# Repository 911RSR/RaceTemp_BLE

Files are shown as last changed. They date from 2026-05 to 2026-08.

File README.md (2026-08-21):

# RaceTemp_BLE

RaceTemp_BLE is an STM32WB55 based Bluetooth Low Energy sensor bridge for
RaceChrono. It reads local sensors, packages the measurements as RaceChrono
DIY CAN/BLE messages, and lets RaceChrono log them as if they came from a CAN
bus.

The project is based on the RaceChrono BLE DIY device idea from Aollin's demo
project:

https://github.com/aollin/racechrono-ble-diy-device

RaceTemp adds the temperature, pressure, thermocouple, RPM, engine-hours, and
engine-revolutions logic used by this project.

## Current Status

This is still a work in progress, but has som "track record" as it's 
the only logger we have used for track days and races in 2026.   

Implemented:

- BLE device name: `RaceTemp`
- RaceChrono-compatible CAN message characteristic
- Optional RaceChrono CAN filter handling
- ADC based MAP and NTC readings
- MAX31855 thermocouple support
- MAX31856 thermocouple support
- Ignition input based RPM measurement
- Engine operating hours counter
- Engine revolutions counter
- Persistent storage of engine counters after the engine stops
- Optional raw measurement snapshot message

## Building
You can download the binary (Release/RaceTemp_BLE.elf) and flash it to an STM32WB55. 
Android field flashing has been tested with STlinkP (Android app), STLINK-V3MINIE, 
and the WeAct STM32WB board. One can of course also flash it via ST-Link and 
STM32CubeProgrammer on a PC.   

If you want to compile yourself on a PC with STM32CubeMX and STM32CubeIDE, then follow this 4-step guide: 
1. Open the project in STM32CubeMX and click "GENERATE CODE".
This should generate some code files and copy some library files.
2. Run the script: .\tools\fix-cubemx-ble-duplicates.ps1
See also my CubeMX-notes at the bottom of this page.
3. Open the project in STM32CubeIDE and build the `Debug` or `Release` configuration.
4. Connect the STLink debug probe and flash the binary.  

The intended BLE security setup is:
- Bonding enabled
- No passkey
- No MITM requirement
- No input/output capability
- Secure connections mandatory
- GATT caching enabled
- Static random address `C0:52:54:42:4C:45`
- Advertisement includes the complete local name `RaceTemp`
- Advertisement includes the RaceChrono DIY service UUID `0x1ff8`

If pairing fails after a firmware or security setting change, delete/forget the
old `RaceTemp` pairing on the phone and pair again.

## Hardware Notes

Target MCU:

- STM32WB55CGU

The project has been developed and tested on a WeAct STM32WB55 board.

Thermocouple IC options:

- MAX31855
- MAX31856

The thermocouple IC is selected at compile time in:

```text
Core/Inc/RaceTemp_config.h
```

## Thermocouple Polarity

Do not trust wire color blindly. For many Type K thermocouples using US/ANSI
colors, yellow is positive and red is negative. Other color standards and probe
suppliers may differ.

A quick practical TC polarity check:

1. Connect the thermocouple.
2. Read the thermocouple channel in RaceChrono.
3. Warm the thermocouple tip with your fingers, hot air, or a lighter from a
   safe distance.
4. If the temperature goes up, the polarity is correct.
5. If the temperature goes down or becomes negative, swap the two thermocouple
   wires.

## Configuring The Thermocouple IC In Firmware

Edit `Core/Inc/RaceTemp_config.h` and set:

```c
#define RACETEMP_THERMOCOUPLE_IC RACETEMP_THERMOCOUPLE_IC_MAX31855
```

or:

```c
#define RACETEMP_THERMOCOUPLE_IC RACETEMP_THERMOCOUPLE_IC_MAX31856
```
For MAX31856, also select the thermocouple type. 
K-Type is most common (for motorsport and exhaust temperature). 

The firmware sends the thermocouple data as raw IC bytes on CAN ID `0x13`.
RaceChrono then decodes those bytes with an equation. This keeps the firmware
simple and makes it possible to inspect status and fault bits from the IC.

## Persistent Engine Counters

PID `21` / CAN ID `0x15` is the stored engine operating time in hours. It is a
lifetime counter, not time since boot. PID `22` / CAN ID `0x16` is the stored
engine revolution counter.

The counters are stored in the last two 4 KB flash pages:

- `0x0807E000`
- `0x0807F000`

The linker script reserves those pages by limiting normal application flash to
`504K`. This makes the firmware image fail to link before it can overlap the
counter storage.

Expected flashing behavior:

- Flashing with "erase necessary pages only" should preserve the counters.
- Flashing with mass erase / full chip erase resets the counters to zero.
- Manually erasing pages `0x0807E000` or `0x0807F000` resets the counters.

The firmware writes the counters to flash when RPM times out after the engine
stops. If the RPM input is left floating during bench testing, false pulses can
increase the counters, so keep the RPM input at a defined level when it is not
connected to a signal source.

## Using With RaceChrono

1. Power the RaceTemp device.
2. Pair the phone with the BLE device named `RaceTemp`.
3. Open RaceChrono.
4. Add/connect it as a RaceChrono BLE DIY/CAN device.
5. Add custom CAN channels for the CAN IDs listed below.
6. Enable the channels you want to log.

RaceChrono may show CAN IDs in either hexadecimal or decimal form. For example,
`0x13` is decimal `19`.

RaceChrono equations are documented here:

https://racechrono.com/support/equations

The thermocouple equations below use RaceChrono's `bitsToInt()` function. In
RaceChrono, bit offset 0 is the most significant bit of payload byte 0.
For the MAX31855 and MAX31856 temperature channels, the recommended equations
below use `bytesToInt()` because they are easier to enter correctly on a phone.

## RaceChrono CAN Channels

Most RaceTemp channels are sent as little-endian 32-bit floats. For those
channels, use this RaceChrono equation:

```text
bytesToFloatLe(raw, 0, 4)
```

| CAN ID | Decimal | Channel | Payload | Unit | RaceChrono equation |
| --- | ---: | --- | --- | --- | --- |
| `0x0B` | 11 | MAP pressure | float32 little-endian | kPa | `bytesToFloatLe(raw, 0, 4)` |
| `0x0C` | 12 | MAP NTC temperature | float32 little-endian | deg C | `bytesToFloatLe(raw, 0, 4)` |
| `0x0D` | 13 | Volvo NTC temperature | float32 little-endian | deg C | `bytesToFloatLe(raw, 0, 4)` |
| `0x0E` | 14 | AC NTC temperature | float32 little-endian | deg C | `bytesToFloatLe(raw, 0, 4)` |
| `0x0F` | 15 | KOSO NTC temperature | float32 little-endian | deg C | `bytesToFloatLe(raw, 0, 4)` |
| `0x10` | 16 | STM32 MCU temperature | float32 little-endian | deg C | `bytesToFloatLe(raw, 0, 4)` |
| `0x11` | 17 | MAP raw ADC value | float32 little-endian | ADC count | `bytesToFloatLe(raw, 0, 4)` |
| `0x12` | 18 | NTC raw ADC value | float32 little-endian | ADC count | `bytesToFloatLe(raw, 0, 4)` |
| `0x13` | 19 | Thermocouple raw data | IC-specific raw bytes | deg C | See thermocouple sections below |
| `0x14` | 20 | Engine speed | float32 little-endian | RPM | `bytesToFloatLe(raw, 0, 4)` |
| `0x15` | 21 | Engine operating time | float32 little-endian | hours | `bytesToFloatLe(raw, 0, 4)` |
| `0x16` | 22 | Engine revolutions | float32 little-endian | rev | `bytesToFloatLe(raw, 0, 4)` |
| `0x17` | 23 | Ignition period | float32 little-endian | timer ticks | `bytesToFloatLe(raw, 0, 4)` |
| `0x18` | 24 | Ignition captures | float32 little-endian | count | `bytesToFloatLe(raw, 0, 4)` |
| `0x19` | 25 | Ignition rejects | float32 little-endian | count | `bytesToFloatLe(raw, 0, 4)` |
| `0x1A` | 26 | EGT temperature | float32 little-endian | deg C | `bytesToFloatLe(raw, 0, 4)` |
| `0x1B` | 27 | Engine speed peak hold | float32 little-endian | RPM | `bytesToFloatLe(raw, 0, 4)` |
| `0x1C` | 28 | EGT peak hold | float32 little-endian | deg C | `bytesToFloatLe(raw, 0, 4)` |
| `0x1D` | 29 | Engine speed filtered | float32 little-endian | RPM | `bytesToFloatLe(raw, 0, 4)` |
| `0x1E` | 30 | Thermocouple status | float32 little-endian | bitmask | `bytesToFloatLe(raw, 0, 4)` |
| `0x1F` | 31 | Thermocouple recoveries | float32 little-endian | count | `bytesToFloatLe(raw, 0, 4)` |
| `0x20` | 32 | Raw measurement snapshot | packed raw bytes | debug | See source layout |
| `0x21` | 33 | RPM fast packet | packed float32 little-endian values | RPM | See RPM fast packet below |

The peak hold channels keep a new maximum value visible for 5 seconds. The RPM
peak hold uses the filtered RPM channel so single noisy periods do not create
false peaks. After 5 seconds without a higher sample, the held channels return
to the current live value.

The filtered RPM channel is calculated from a short recent ignition-period
window with outlier trimming. It is intended for the driver display. The raw RPM
channel remains useful for ignition pickup debugging.

## RPM Fast Packet

CAN ID `0x21` is sent at 25 Hz. It packs the driver-facing RPM values into one
BLE notification:

| Offset | Channel | Unit | RaceChrono equation |
| ---: | --- | --- | --- |
| 0 | RPM raw | RPM | `bytesToFloatLe(raw, 0, 4)` |
| 4 | RPM filtered | RPM | `bytesToFloatLe(raw, 4, 4)` |
| 8 | RPM peak hold | RPM | `bytesToFloatLe(raw, 8, 4)` |

The individual RPM and ignition debug channels remain available at the slower
sensor publishing rate for comparison and troubleshooting.

Thermocouple status is a bitmask:

- `1`: current EGT sample is valid
- `2`: SPI/read error
- `4`: thermocouple IC fault bit set
- `8`: MAX31856 config readback mismatch/error
- `16`: recovery was triggered on this sample
- `32`: implausible thermocouple temperature

When the thermocouple sample is invalid, the EGT channel sends `0 C`. This
is intentionally obvious in the driver display and logs; the firmware does not
hold the last good EGT value.

## Reading MAX31855 In RaceChrono

When `RACETEMP_THERMOCOUPLE_IC_MAX31855` is selected, CAN ID `0x13` contains
the four raw bytes read from the MAX31855. The byte order is the same as the IC
SPI transfer: most significant byte first.

The MAX31855 thermocouple temperature is a signed 14-bit value with
0.25 deg C per bit.

Recommended RaceChrono equation:

```text
bytesToInt(raw, 0, 2) / 16.0
```

Equivalent bitfield equation:

```text
bitsToInt(raw, 0, 14) * 0.25
```

The `bytesToInt()` version works because the MAX31855 thermocouple value is
left-aligned in the first two raw bytes.

Useful notes:

- The MAX31855 fault flag is bit D16 of the 32-bit raw value.
- The low bits contain the IC-specific fault details.
- A separate RaceChrono status channel can use `bytesToUint(raw, 3, 1)` to show
  the lowest raw byte.
- If the thermocouple channel shows unrealistic values, first confirm that the
  RaceTemp firmware is built for MAX31855 and not MAX31856.

## Reading MAX31856 In RaceChrono

When `RACETEMP_THERMOCOUPLE_IC_MAX31856` is selected, CAN ID `0x13` contains
four bytes:

| Payload byte | Contents |
| ---: | --- |
| 0 | MAX31856 `LTCBH` register |
| 1 | MAX31856 `LTCBM` register |
| 2 | MAX31856 `LTCBL` register |
| 3 | MAX31856 fault/status register |

The MAX31856 thermocouple temperature is a signed 19-bit value with
0.0078125 deg C per bit.

Recommended RaceChrono equation:

```text
bytesToInt(raw, 0, 3) / 4096.0
```

Equivalent bitfield equation:

```text
bitsToInt(raw, 0, 19) * 0.0078125
```

The `bytesToInt()` version works because the MAX31856 thermocouple value is
left-aligned in the first three raw bytes.

Useful notes:

- Select the correct thermocouple type in `RaceTemp_config.h`.
- Payload byte 3 is the MAX31856 fault/status register.
- A separate RaceChrono status channel can use `bytesToUint(raw, 3, 1)`.
- If the temperature is wrong but changes with heat, check the selected
  thermocouple type first.
- If the value is completely wrong, confirm that RaceChrono is using the
  MAX31856 equation and not the MAX31855 equation.

## Raw Measurement Snapshot

CAN ID `0x20` is intended for development and debugging. It sends one packed
snapshot of the raw measurement buffer:

- ADC samples
- Thermocouple SPI bytes
- Ignition timing data

Normal RaceChrono logging should usually use the individual channels instead.
The raw snapshot is useful when checking new sensors or debugging conversion
logic.

## Notes About CubeMX Regeneration

Unfortunately the current version of CubeMX can make some mistakes (it can duplicate user-section
content in the BLE files), and some generated files contain project-specific
settings. After regenerating the code, run the cleanup script before building:

```powershell
powershell -ExecutionPolicy Bypass -File .\tools\fix-cubemx-ble-duplicates.ps1
```

The script removes duplicate CubeMX generated BLE functions, restores the
RaceChrono BLE callbacks, restores the BLE security/address settings used by
this project, and repairs the local linker script.

Important local linker-script repairs:

- Normal application flash is limited to `504K`.
- `PERSIST` reserves the last two 4 KB flash pages for engine counters.
- `MAPPING_TABLE` is placed at `0x20030000`.
- `MB_MEM1` and `.MB_MEM2` are placed in the CPU2 shared RAMB area.
- `.MB_MEM2` is 4-byte aligned so startup initialization does not fault.

The script also removes the extra generated HSEM lock before `MX_APPE_Init()`.
Leaving that duplicate lock in place can stall BLE startup or lead to an early
HardFault.

To re-generate the code from CubeMX:

1. Open the .ioc file in CubeMX and click "GENERATE CODE"
2. Run `tools/fix-cubemx-ble-duplicates.ps1`
3. Build in STM32CubeIDE
4. Check that pairing still works with `RaceTemp`

Keep project-specific RaceTemp logic in the RaceTemp source files where
possible. This reduces the amount of code that lives inside CubeMX user
sections.

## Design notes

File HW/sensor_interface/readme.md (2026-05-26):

A sensor interface PCB designed and ordered on NiNo's 22 years birthday.  
The PCB has four inputs: 
1) RPM -- engine speed
2) EGT -- exhaust gas temperature
3) NTC1 -- water temperature 
4) NTC2 -- cylinder head temperature
   
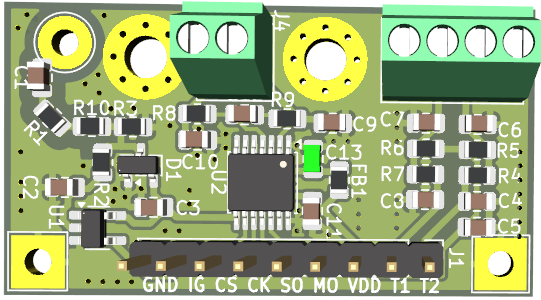
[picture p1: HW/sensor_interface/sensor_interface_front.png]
front side
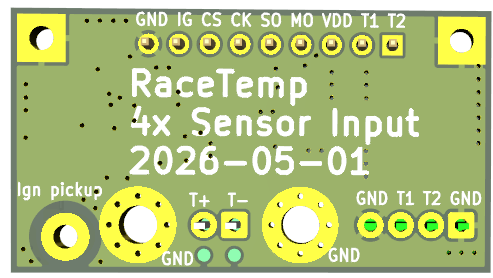
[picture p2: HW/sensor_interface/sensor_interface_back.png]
back side


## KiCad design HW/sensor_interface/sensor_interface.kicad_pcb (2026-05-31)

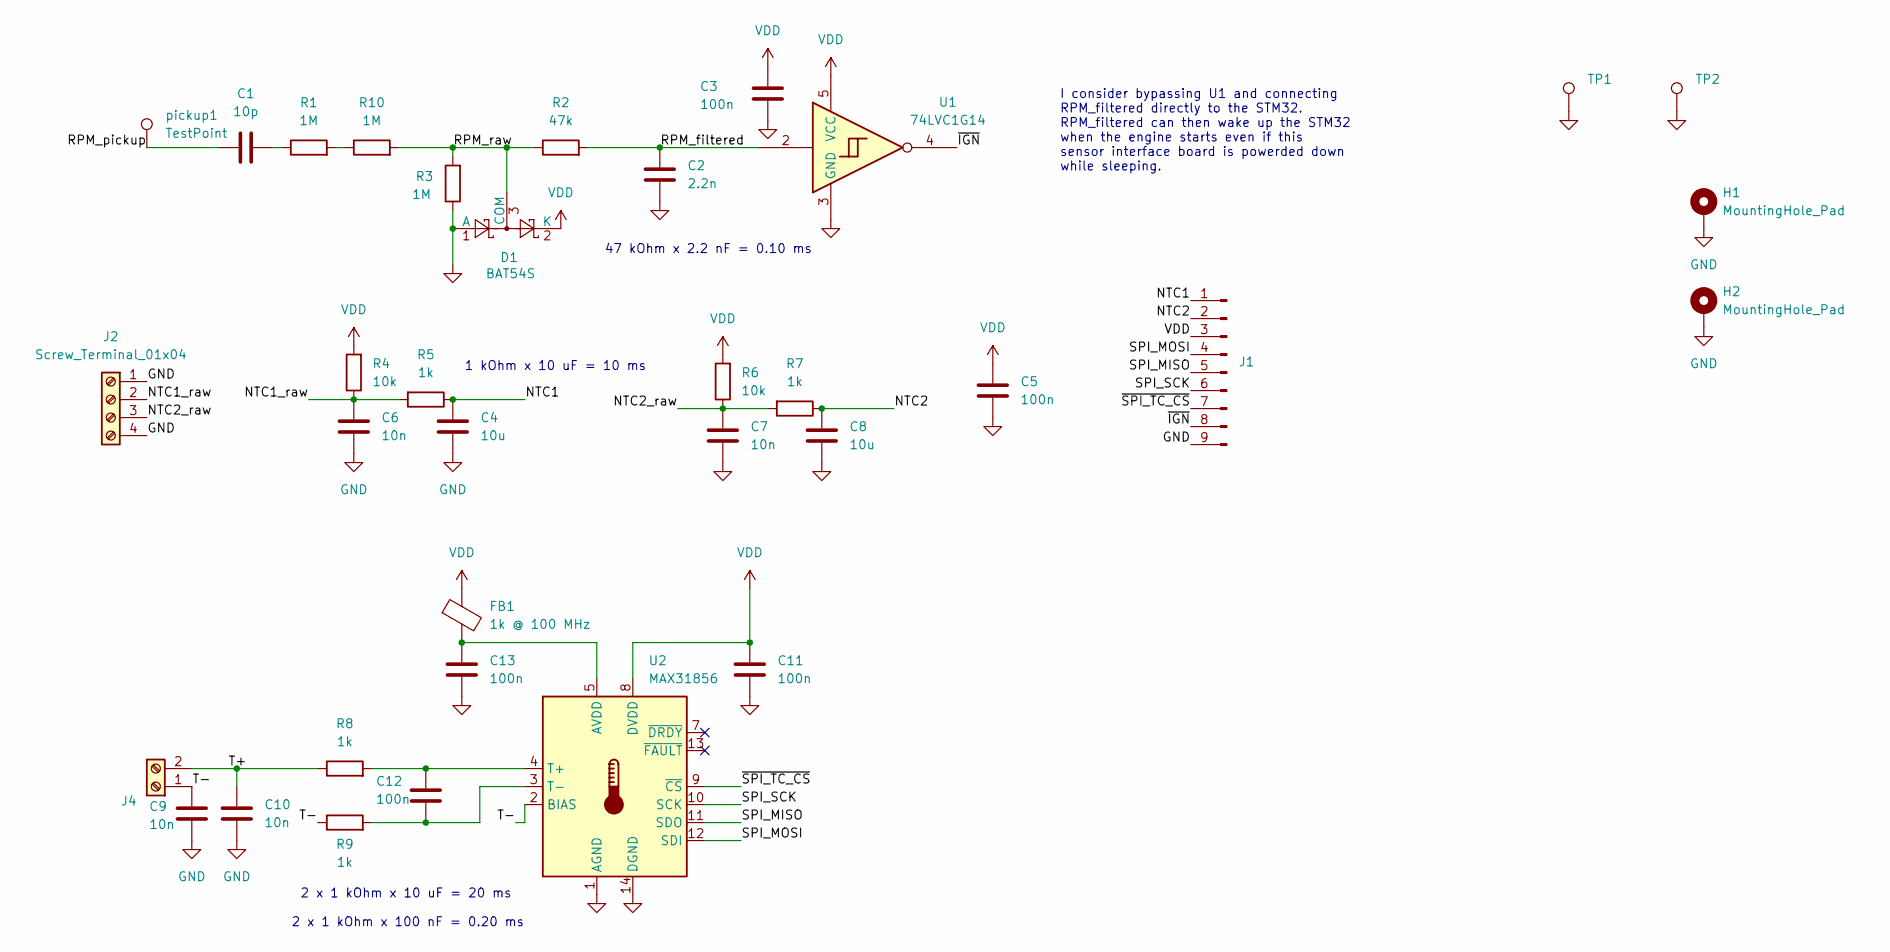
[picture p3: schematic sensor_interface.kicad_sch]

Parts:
C1: 10p; C_0805_2012Metric; MPN CC0805JRNPOCBN100
C2: 2.2n; C_0805_2012Metric; MPN C0805C222KAGECAUTO
C3, C5, C11, C12, C13: 100n; C_0805_2012Metric
C4, C8: 10u; C_0805_2012Metric
C6, C7, C9, C10: 10n; C_0805_2012Metric
D1: BAT54S; SOT-23; MPN BAT54S
FB1: 1k @ 100 MHz; R_0805_2012Metric
H1, H2: MountingHole_Pad; MountingHole_3.2mm_M3_Pad_Via
J1: Berg; PinHeader_1x09_P2.54mm_Vertical
J2: Screw_Terminal_01x04; TerminalBlock_Phoenix_MPT-0,5-4-2.54_1x04_P2.54mm_Horizontal
J4: Screw_Terminal; TerminalBlock_Phoenix_MPT-0,5-2-2.54_1x02_P2.54mm_Horizontal
R1: 1M; R_0805_2012Metric; MPN CRCW08051M00FKEA
R2: 47k; R_0805_2012Metric
R3, R10: 1M; R_0805_2012Metric
R4, R6: 10k; R_0805_2012Metric
R5, R7, R8, R9: 1k; R_0805_2012Metric
TP1, TP2: TestPoint; TestPoint_THTPad_4.0x4.0mm_Drill2.0mm
U1: 74LVC1G14; SOT-23-5_HandSoldering
U2: MAX31856; TSSOP-14_4.4x5mm_P0.65mm; MPN MAX31856MUD+T
pickup1: TestPoint; TestPoint_THTPad_D4.0mm_Drill2.0mm

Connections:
/NTC1: C4.2, J1.1, R5.1
/NTC1_raw: C6.2, J2.2, R4.1, R5.2
/NTC2: C8.2, J1.2, R7.1
/NTC2_raw: C7.2, J2.3, R6.1, R7.2
/RPM_filtered: C2.2, R2.2, U1.2
/RPM_pickup: C1.1, pickup1.1 (1_1)
/RPM_raw: D1.3 (COM), R2.1, R3.2, R10.2
/SPI_MISO: J1.5, U2.11 (SDO)
/SPI_MOSI: J1.4, U2.12 (SDI)
/SPI_SCK: J1.6, U2.10 (SCK)
/T+: C10.2, J4.2, R8.1
/T-: C9.2, J4.1, R9.1, U2.2 (BIAS)
/~IGN: J1.8, U1.4
/~SPI_TC_CS: J1.7, U2.9 (~CS)
GND: C2.1, C3.1, C4.1, C5.1, C6.1, C7.1, C8.1, C9.1, C10.1, C11.1, C13.1, D1.1 (A), H1.1 (1_1), H2.1 (1_1), J1.9, J2.1, J2.4, R3.1, TP1.1 (1_1), TP2.1 (1_1), U1.3 (GND), U2.1 (AGND), U2.14 (DGND)
unnamed: C1.2, R1.1
unnamed: R1.2, R10.1
unnamed: C13.2, FB1.2, U2.5 (AVDD)
unnamed: C12.2, R8.2, U2.4 (T+)
unnamed: C12.1, R9.2, U2.3 (T-)
VDD: C3.2, C5.2, C11.2, D1.2 (K), FB1.1, J1.3, R4.2, R6.2, U1.5 (VCC), U2.8 (DVDD)

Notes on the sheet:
2 x 1 kOhm x 10 uF = 20 ms
I consider bypassing U1 and connecting RPM_filtered directly to the STM32. RPM_filtered can then wake up the STM32 when the engine starts even if this sensor interface board is powerded down while sleeping.
47 kOhm x 2.2 nF = 0.10 ms
2 x 1 kOhm x 100 nF = 0.20 ms
1 kOhm x 10 uF = 10 ms

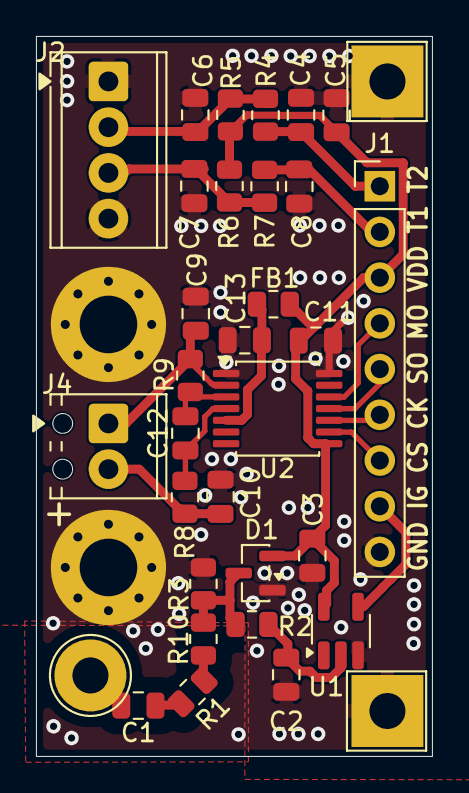
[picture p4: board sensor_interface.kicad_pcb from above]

Board: 2 copper layers, 22.0 x 40.0 mm, 35 parts (0 on the bottom side), 21 nets.

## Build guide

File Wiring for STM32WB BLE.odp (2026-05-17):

## Debugger Connections

USART1_RX

USART2_TX

Showing both sides of a

STM32 V3MINIE debugger

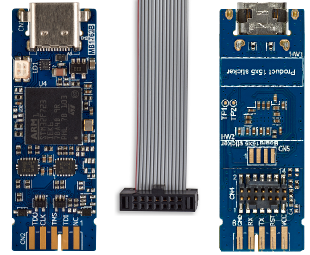
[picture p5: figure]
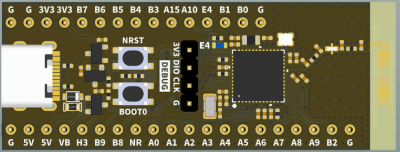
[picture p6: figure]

## Simple/Easy RaceTemp with only Thermocouple, MAP and NTC

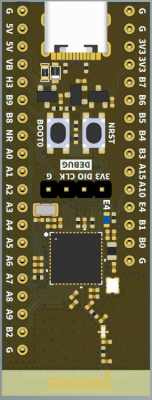
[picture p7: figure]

No shielding or decoupling – electric noise can cause problems here, both for the BLE connection and for ADC/sensor accuracy.

Bat Neg = G

Bat Pos = 5V

A0

MAP = A1

NTC = A2

MAP VCC & 1kΩ to NTC = A3

TC NSS = SPI1_NSS = A4

TC SCK = SPI1_SCK = A5

TC SO = SPI1_MISO = A6

SPI1_MOSI = A7

TC VCC = A8

A9

B2

TC GND = G

G

G

3V3

3V3

B7 = USART1_RX

B6 = USART2_TX

B5 = SWO

B4

B3

A15

A10

E4

B1

B0

G = Pres GND

## EMI Instructions

- Put the battery and the STM32-board inside a shielded box that will be our “chassis” and ground reference. My “shielded box” is a waterproof plastic box with inside lining of aluminium foil tape. Connect Bat. Neg. and STM32 GND to chassis (the aluminium lining). Insulating tape glue? Tape with overlap and it will anyway shield in MHz-range!
- Place the BLE antenna next to a window in the aluminium tape. The antenna shall be located/oriented away from wires and electric noise. Do not place the antenna next to the ignition probe.
- Add a 100 nF ceramic capacitor to chassis to every wire entering/exiting the shielded box. Those capacitors shall be located as close as possible to the wire exit location in the box and connect to the same piece of tape as the GND (not connected via tape overlap, as the glue might be a DC isolator). See example below for a NTC.
- Consider using twisted pair wires and shielded wires!

100 nF

I designed a PCB with sensor input frontend for:

- Thermocouple (Exhaust Temp)
- 2 pcs NTC (Water or Oil Temp)
- RPM (Capacitive HV pickup)

That PCB makes the wiring much easier and more robust with respect to EMI.

GND

NTC

10 nF

## Full Featured RaceTemp with Lambda, EGT, MPU, GPS, RPM, NTC, WaterTemp and more

...but without CAN

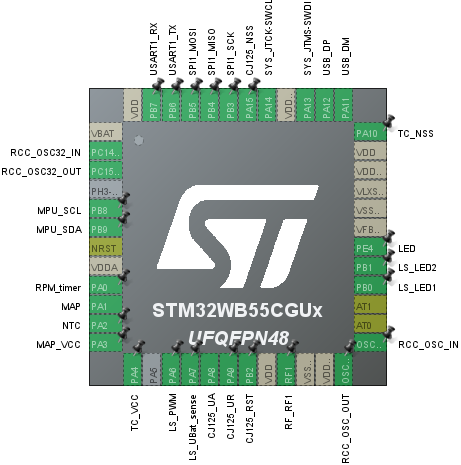
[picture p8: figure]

Bat Neg = G

Bat Pos = 5V

RPM_timer = A0

MAP = A1

NTC = A2

MAP VCC & 10kΩ to NTC = A3

TC VCC = A4

A5

LS_PWM = A6

LS_UBat_sense = A7

CJ125_UA = A8

CJ125_UR = A9

CJ125_RST = B2

TC GND = G

G = Chassis/box ?

G

3V3

3V3

B7 = USART1_RX

B6 = USART2_TX

B5 = SPI1_MOSI

B4 = SPI1_MISO

B3 = SPI1_SCK

A15 = CJ125_NSS

A10 = TC_NSS

E4 = LED (on board)

B1 = LS_LED2

B0 = LS_LED1

G = Pres GND

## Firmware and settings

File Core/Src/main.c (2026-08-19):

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
/* Includes ------------------------------------------------------------------*/
#include "main.h"
#include "adc.h"
#include "crc.h"
#include "dma.h"
#include "i2c.h"
#include "ipcc.h"
#include "rf.h"
#include "rtc.h"
#include "spi.h"
#include "tim.h"
#include "usb_device.h"
#include "gpio.h"

/* USER CODE BEGIN Includes */
//#include "usbd_cdc_if.h"
//#include "custom_app.h"
//#include "stm32_seq.h"

/* USER CODE END Includes */


/* USER CODE BEGIN PV */
volatile uint8_t spiRxBuffer[4];
volatile RCC_OscInitTypeDef racetemp_debug_rcc_osc_init;
volatile HAL_StatusTypeDef racetemp_debug_rcc_osc_status;
/* USER CODE END PV */

void SystemClock_Config(void);
void PeriphCommonClock_Config(void);
/* USER CODE BEGIN 0 */
static void RaceTemp_EarlyLedInit(void)
{
  GPIO_InitTypeDef GPIO_InitStruct = {0};

  __HAL_RCC_GPIOE_CLK_ENABLE();
  GPIO_InitStruct.Pin = LED_Pin;
  GPIO_InitStruct.Mode = GPIO_MODE_OUTPUT_PP;
  GPIO_InitStruct.Pull = GPIO_NOPULL;
  GPIO_InitStruct.Speed = GPIO_SPEED_FREQ_LOW;
  HAL_GPIO_Init(LED_GPIO_Port, &GPIO_InitStruct);
  HAL_GPIO_WritePin(LED_GPIO_Port, LED_Pin, GPIO_PIN_SET);
}

static void RaceTemp_MainLoopHeartbeat(void)
{
  static uint32_t last_toggle_tick;
  uint32_t now_tick = HAL_GetTick();

  if ((now_tick - last_toggle_tick) >= 500U)
  {
    last_toggle_tick = now_tick;
    HAL_GPIO_TogglePin(LED_GPIO_Port, LED_Pin);
  }
}

/* USER CODE END 0 */

/**
  * @brief  The application entry point.
  * @retval int
  */
int main(void)
{

  /* MCU Configuration--------------------------------------------------------*/

  /* Reset of all peripherals, Initializes the Flash interface and the Systick. */
  HAL_Init();
  /* Config code for STM32_WPAN (HSE Tuning must be done before system clock configuration) */
  MX_APPE_Config();

  /* USER CODE BEGIN Init */
  LL_HSEM_1StepLock( HSEM, 5);
  /* USER CODE END Init */

  /* Configure the system clock */
  SystemClock_Config();

  /* Configure the peripherals common clocks */
  PeriphCommonClock_Config();

  /* IPCC initialisation */
  MX_IPCC_Init();

  /* Initialize all configured peripherals */
  MX_GPIO_Init();
  MX_DMA_Init();
  MX_RTC_Init();
  MX_USB_Device_Init();
  MX_ADC1_Init();
  MX_CRC_Init();
  MX_SPI1_Init();
  MX_TIM1_Init();
  MX_TIM2_Init();
  MX_I2C1_Init();
  MX_TIM16_Init();
  MX_RF_Init();
  /* USER CODE BEGIN 2 */
  RaceTemp_EarlyLedInit();


  /* USER CODE END 2 */

  /* Init code for STM32_WPAN */
  MX_APPE_Init();

  /* Infinite loop */
  /* USER CODE BEGIN WHILE */
  while (1)
  {
    /* USER CODE END WHILE */
    MX_APPE_Process();

    /* USER CODE BEGIN 3 */
    RaceTemp_MainLoopHeartbeat();
  }
  /* USER CODE END 3 */
}

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


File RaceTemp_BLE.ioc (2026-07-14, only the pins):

Mcu.UserName=STM32WB55CGUx
PA0.GPIO_Label=RPM_timer
PA0.Signal=S_TIM2_CH1
PA1.GPIO_Label=MAP
PA1.Signal=ADCx_IN6
PA10.GPIO_Label=TC_NSS
PA10.Signal=GPIO_Output
PA11.Signal=USB_DM
PA12.Signal=USB_DP
PA13.Signal=SYS_JTMS-SWDIO
PA14.Signal=SYS_JTCK-SWCLK
PA15.GPIO_Label=CJ125_NSS
PA15.Signal=GPIO_Output
PA2.GPIO_Label=NTC
PA2.Signal=ADCx_IN7
PA3.GPIO_Label=MAP_VCC
PA3.Signal=GPIO_Output
PA4.GPIO_Label=TC_VCC
PA4.Signal=GPIO_Output
PA6.GPIO_Label=LS_PWM
PA6.Signal=S_TIM16_CH1
PA7.GPIO_Label=LS_UBat_sense
PA7.Signal=ADCx_IN12
PA8.GPIO_Label=CJ125_UA
PA8.Signal=ADCx_IN15
PA9.GPIO_Label=CJ125_UR
PA9.Signal=ADCx_IN16
PB0.GPIO_Label=LS_LED1
PB0.Signal=GPIO_Output
PB1.GPIO_Label=LS_LED2
PB1.Signal=GPIO_Output
PB2.GPIO_Label=CJ125_RST
PB2.Signal=GPIO_Output
PB3.Signal=SPI1_SCK
PB4.Signal=SPI1_MISO
PB5.Signal=SPI1_MOSI
PB6.Signal=USART1_TX
PB7.Signal=USART1_RX
PB8.GPIO_Label=MPU_SCL
PB8.Signal=I2C1_SCL
PB9.GPIO_Label=MPU_SDA
PB9.Signal=I2C1_SDA
PC14-OSC32_IN.Signal=RCC_OSC32_IN
PC15-OSC32_OUT.Signal=RCC_OSC32_OUT
PE4.GPIO_Label=LED
PE4.Signal=GPIO_Output

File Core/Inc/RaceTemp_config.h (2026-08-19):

/*
 * RaceTemp_config.h
 *
 * Project-local RaceTemp configuration.
 */

#ifndef RACETEMP_CONFIG_H_
#define RACETEMP_CONFIG_H_

#define RACETEMP_THERMOCOUPLE_IC_MAX31855  1
#define RACETEMP_THERMOCOUPLE_IC_MAX31856  2

#define RACETEMP_THERMOCOUPLE_IC RACETEMP_THERMOCOUPLE_IC_MAX31856
#ifndef RACETEMP_THERMOCOUPLE_IC
#define RACETEMP_THERMOCOUPLE_IC RACETEMP_THERMOCOUPLE_IC_MAX31855
#endif

#define RACETEMP_MAX31856_TC_TYPE_B 0x00
#define RACETEMP_MAX31856_TC_TYPE_E 0x01
#define RACETEMP_MAX31856_TC_TYPE_J 0x02
#define RACETEMP_MAX31856_TC_TYPE_K 0x03
#define RACETEMP_MAX31856_TC_TYPE_N 0x04
#define RACETEMP_MAX31856_TC_TYPE_R 0x05
#define RACETEMP_MAX31856_TC_TYPE_S 0x06
#define RACETEMP_MAX31856_TC_TYPE_T 0x07

#ifndef RACETEMP_MAX31856_TC_TYPE
#define RACETEMP_MAX31856_TC_TYPE RACETEMP_MAX31856_TC_TYPE_K
#endif

/* Signed 0.0625 deg C steps; calibrated for the currently fitted device. */
#ifndef RACETEMP_MAX31856_CJ_OFFSET_STEPS
#define RACETEMP_MAX31856_CJ_OFFSET_STEPS (-50)
#endif
#if (RACETEMP_MAX31856_CJ_OFFSET_STEPS < -128) || (RACETEMP_MAX31856_CJ_OFFSET_STEPS > 127)
#error "RACETEMP_MAX31856_CJ_OFFSET_STEPS must fit in a signed 8-bit CJTO register"
#endif

#ifndef RACETEMP_RPM_TIMER_HZ
#define RACETEMP_RPM_TIMER_HZ 16000000.0f
#endif

#ifndef RACETEMP_IGNITION_PULSES_PER_REV
#define RACETEMP_IGNITION_PULSES_PER_REV 1.0f
#endif

#ifndef RACETEMP_RPM_MAX
#define RACETEMP_RPM_MAX 20000.0f
#endif

#ifndef RACETEMP_RPM_MIN_PERIOD_TICKS
#define RACETEMP_RPM_MIN_PERIOD_TICKS ((uint32_t)((60.0f * RACETEMP_RPM_TIMER_HZ) / (RACETEMP_RPM_MAX * RACETEMP_IGNITION_PULSES_PER_REV)))
#endif

#ifndef RACETEMP_RPM_TIMEOUT_TICKS
#define RACETEMP_RPM_TIMEOUT_TICKS ((uint32_t)(2.0f * RACETEMP_RPM_TIMER_HZ))
#endif

#ifndef RACETEMP_RPM_ESTIMATOR_PERIODS
#define RACETEMP_RPM_ESTIMATOR_PERIODS 6U
#endif
#if (RACETEMP_RPM_ESTIMATOR_PERIODS < 2U) || (RACETEMP_RPM_ESTIMATOR_PERIODS > 8U)
#error "RACETEMP_RPM_ESTIMATOR_PERIODS must be between 2 and 8"
#endif

#ifndef RACETEMP_RPM_ESTIMATOR_MAX_WINDOW_TICKS
#define RACETEMP_RPM_ESTIMATOR_MAX_WINDOW_TICKS ((uint32_t)(0.080f * RACETEMP_RPM_TIMER_HZ))
#endif

#ifndef RACETEMP_FAST_TICK_HZ
#define RACETEMP_FAST_TICK_HZ 100U
#endif

#ifndef RACETEMP_RPM_FAST_PUBLISH_DIVIDER
#define RACETEMP_RPM_FAST_PUBLISH_DIVIDER 4U
#endif

#ifndef RACETEMP_SLOW_PUBLISH_DIVIDER
#define RACETEMP_SLOW_PUBLISH_DIVIDER 10U
#endif

#ifndef RACETEMP_PEAK_HOLD_TICKS
#define RACETEMP_PEAK_HOLD_TICKS ((uint32_t)(5.0f * RACETEMP_RPM_TIMER_HZ))
#endif

#ifndef RACETEMP_TC_RECOVERY_BAD_READS
#define RACETEMP_TC_RECOVERY_BAD_READS 3U
#endif

#ifndef RACETEMP_TC_POWER_RECOVERY_BAD_READS
#define RACETEMP_TC_POWER_RECOVERY_BAD_READS 10U
#endif

#ifndef RACETEMP_TC_POWER_CYCLE_DELAY_MS
#define RACETEMP_TC_POWER_CYCLE_DELAY_MS 10U
#endif

#ifndef RACETEMP_TC_INVALID_TEMPERATURE_C
#define RACETEMP_TC_INVALID_TEMPERATURE_C (0.0f)
#endif

#ifndef RACETEMP_TC_MIN_VALID_TEMPERATURE_C
#define RACETEMP_TC_MIN_VALID_TEMPERATURE_C (0.0f)
#endif

#ifndef RACETEMP_STATUS_LED_NORMAL_PERIOD_TICKS
#define RACETEMP_STATUS_LED_NORMAL_PERIOD_TICKS RACETEMP_FAST_TICK_HZ
#endif

#ifndef RACETEMP_STATUS_LED_NORMAL_ON_TICKS
#define RACETEMP_STATUS_LED_NORMAL_ON_TICKS 10U
#endif

#ifndef RACETEMP_STATUS_LED_FAULT_PERIOD_TICKS
#define RACETEMP_STATUS_LED_FAULT_PERIOD_TICKS (RACETEMP_FAST_TICK_HZ / 4U)
#endif

#ifndef RACETEMP_STATUS_LED_FAULT_ON_TICKS
#define RACETEMP_STATUS_LED_FAULT_ON_TICKS 5U
#endif

#ifndef RACETEMP_ENGINE_REVS_PER_IGNITION_PULSE
#define RACETEMP_ENGINE_REVS_PER_IGNITION_PULSE 1U
#endif

#ifndef RACETEMP_COUNTER_FLASH_BASE
/* Last two 4 KB flash pages. Keep this aligned with STM32WB55CGUX_FLASH.ld. */
#define RACETEMP_COUNTER_FLASH_BASE 0x0807E000UL
#endif

#ifndef RACETEMP_COUNTER_FLASH_PAGES
#define RACETEMP_COUNTER_FLASH_PAGES 2U
#endif

#endif /* RACETEMP_CONFIG_H_ */

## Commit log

2025-08-28 CTS (clear to send) for USART1. Makefile with correct startup.s and linker script. Added (and commented out) a Makefile rule for CubeMX code generation via command line interface and script.
    [RaceTemp_BLE.ioc]
2026-03-30 Add README content for RaceTemp_BLE
    Added detailed information about the BLE version of RaceTemp, including supported features, ADC connections, and CAN ID configurations.
2026-04-02 Revise README for project status and sensor support
    Updated README to clarify project status and features.
2026-04-03 Should work with latest/current ST tools and libraries, but note:
    1: If it goes directly to HardFault_Handler(), then it might be a
    problem with shared RAM allocation in the auto generated FLASh.ld-file.
    I added a binary (Release/RaceTemp_BLE.elf.elf) which can be flashed
    with STM32CubeProgrammer. That binary is using an old FLASh.ld-file,
    and does not have that HardFault problem.
    2: I have only tested the binary with the BLE firmware
    "stm32wb5x_BLE_Stack_full_extended_fw.bin"
    from STM32Cube_FW_WB_V1.24.0. (I used the Radio/BLE menu in
    STM32CubeProgrammer to flash the new FUS and FW.)
    3: It does not reconnect automatically like it should after a
    loss of connection (e.g. out of range or a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
    [RaceTemp.c, RaceTemp.h, RaceTemp_BLE.ioc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]
2026-05-15 Add files via upload
    A sensor interface PCB designed and ordered on NiNo's 22 years birthday.
    The PCB has four inputs:
    1) RPM -- engine speed
    2) EGT -- exhaust gas temperature
    3) NTC1 -- water temperature
    4) NTC2 -- cylinder head temperature
    [sensor_interface.kicad_pcb, sensor_interface.kicad_sch]
2026-05-26 Update readme with PCB images
    Added images of the front and back sides of the PCB to the readme.
2026-05-26 Improve formatting in sensor_interface readme
    Formatted the readme for better readability.
2026-05-27 Cleaned up text on F.Fab
    [sensor_interface.kicad_pcb]
2026-05-27 Update sensor_interface.kicad_sch
    Changed some capacitor and resistor values.
    [sensor_interface.kicad_sch]
2026-05-27 Update sensor_interface.kicad_pcb
    Fixed a missing trace/connection to U2 pin 3.
    [sensor_interface.kicad_pcb]
2026-05-31 fixed issue: kicad_pcb was not showing the PCB
    [sensor_interface.kicad_pcb]
2026-06-22 Add MAX31856 diagnostics and CJ calibration
2026-06-30 Update BLE pairing and sensor pull-ups
    [sensor_interface.kicad_sch]
2026-07-01 RPM input values: C1=1n, C2=DNP
    [sensor_interface.kicad_sch]
2026-08-19 Fix RaceChrono BLE advertising setup
    Document the BLE/linker settings restored after CubeMX regeneration, advertise the RaceChrono DIY service UUID with the RaceTemp name, use a stable static random BLE address, keep the startup LED visible, and add HardFault capture state for debugger diagnosis.
    [RaceTemp_config.h, app_conf.h, main.c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]
2026-08-21 Enhance README with detailed build instructions
    Updated instructions for building the project, including details on flashing and compiling with STM32CubeMX and STM32CubeIDE.

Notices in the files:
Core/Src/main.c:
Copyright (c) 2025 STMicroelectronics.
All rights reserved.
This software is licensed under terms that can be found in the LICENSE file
